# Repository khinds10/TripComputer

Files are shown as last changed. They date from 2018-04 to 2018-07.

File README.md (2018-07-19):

# TripComputer - GPS Trip Computer & Weather Module for your vehicle

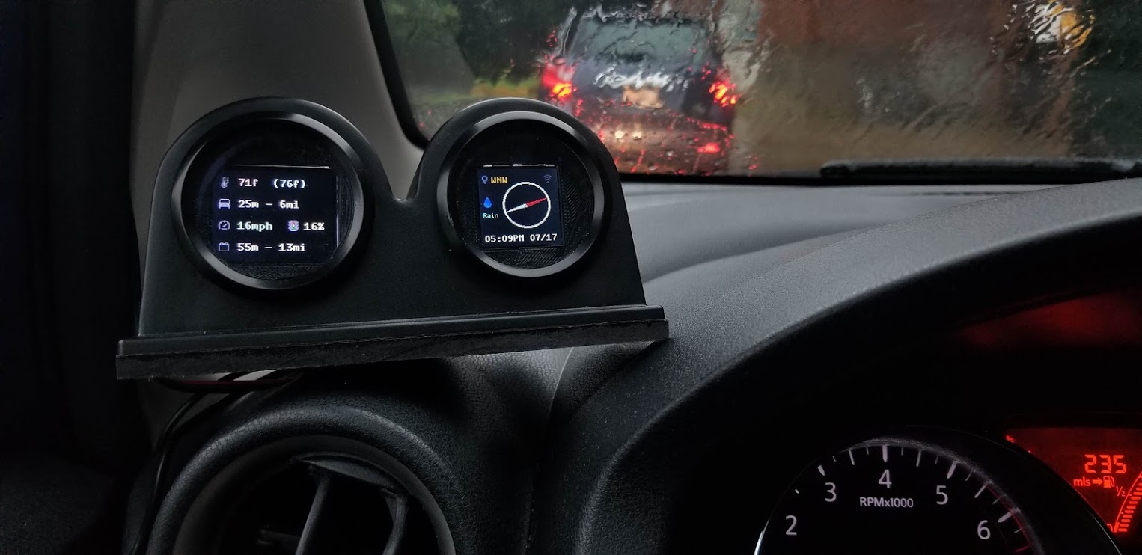
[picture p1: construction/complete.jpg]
Completed


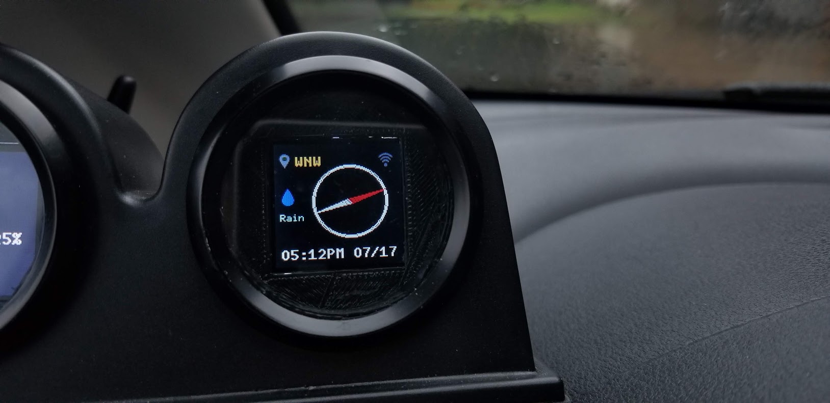
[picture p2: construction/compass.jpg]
Compass


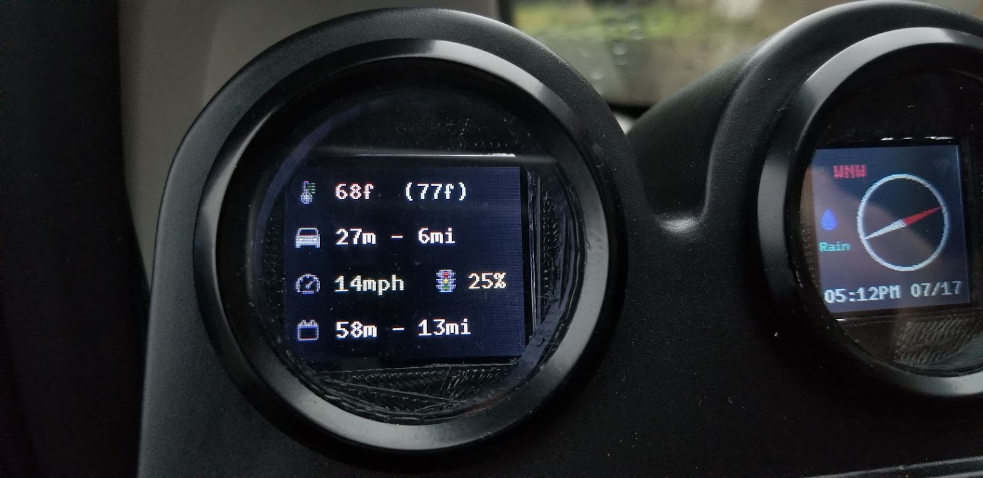
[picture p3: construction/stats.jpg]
Driving Statistics


#### Flashing RaspberriPi Hard Disk / Install Required Software (Using Ubuntu Linux)

Download "RASPBIAN JESSIE LITE VERSION"
https://www.raspberrypi.org/downloads/raspbian/

**Create your new hard disk for DashboardPI**
>Insert the microSD to your computer via USB adapter and create the disk image using the `dd` command
>
> Locate your inserted microSD card via the `df -h` command, unmount it and create the disk image with the disk copy `dd` command
> 
> $ `df -h`
> */dev/sdb1       7.4G   32K  7.4G   1% /media/XXX/1234-5678*
> 
> $ `umount /dev/sdb1`
> 
> **Caution: be sure the command is completely accurate, you can damage other disks with this command**
> 
> *if=location of RASPBIAN JESSIE FULL VERSION image file*
> *of=location of your microSD card*
> 
> $ `sudo dd bs=4M if=/path/to/raspbian-jessie-lite.img of=/dev/sdb`
> *(note: in this case, it's /dev/sdb, /dev/sdb1 was an existing factory partition on the microSD)*

**Setting up your RaspberriPi**

*Insert your new microSD card to the raspberrypi and power it on with a monitor connected to the HDMI port*

Login
> user: **pi**
> pass: **raspberry**

Change your account password for security (from terminal)
>`sudo passwd pi`

Enable RaspberriPi Advanced Options (from terminal)
>`sudo raspi-config`

Choose:
`1 Expand File System`

`9 Advanced Options`
>`A2 Hostname`
>*change it to "TripComputer"*
>
>`A4 SSH`
>*Enable SSH Server*
>
>`A7 I2C`
>*Enable i2c interface*

**Enable the English/US Keyboard**

>`sudo nano /etc/default/keyboard`

> Change the following line:
>`XKBLAYOUT="us"`

**Reboot PI for Keyboard layout changes / file system resizing to take effect**
>$ `sudo shutdown -r now`

**Auto-Connect to your WiFi**

>`sudo nano /etc/wpa_supplicant/wpa_supplicant.conf`

Add the following lines to have your raspberrypi automatically connect to your home WiFi
*(if your wireless network is named "linksys" for example, in the following example)*

	network={
	   ssid="linksys"
	   psk="WIRELESS PASSWORD HERE"
	}

**Reboot PI to connect to WiFi network**

>$ `sudo shutdown -r now`
>
>Now that your PI is finally on the local network, you can login remotely to it via SSH.
>But first you need to get the IP address it currently has.
>
>$ `ifconfig`
>*Look for "inet addr: 192.168.XXX.XXX" in the following command's output for your PI's IP Address*

**Go to another machine and login to your raspberrypi via ssh**

> $ `ssh pi@192.168.XXX.XXX`

**Start Installing required packages**

>$ `sudo apt-get update && sudo apt-get upgrade`
>
>$ `sudo apt-get install build-essential git gpsd gpsd-clients i2c-tools libi2c-dev python3 python3-pip python-dev python-gps python-imaging python-pip python-smbus rpi.gpio vim python-psutil`
>
>$ `sudo pip install RPi.GPIO`

**Update local timezone settings**

>$ `sudo dpkg-reconfigure tzdata`

`select your timezone using the interface`

**Setup the simple directory `l` command [optional]**

>`vi ~/.bashrc`
>
>*add the following line:*
>
>`alias l='ls -lh'`
>
>`source ~/.bashrc`

**Fix VIM default syntax highlighting [optional]**

>`sudo vi  /etc/vim/vimrc`
>
>uncomment the following line:
>
>_syntax on_

### Supplied needed

2" 320x240 TFT LCD Digole Display (x2)

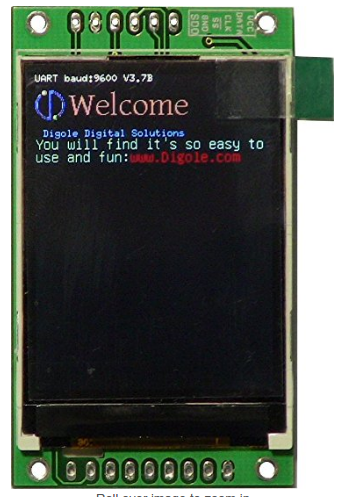
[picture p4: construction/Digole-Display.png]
Digole Display


DHT11 Humidistat

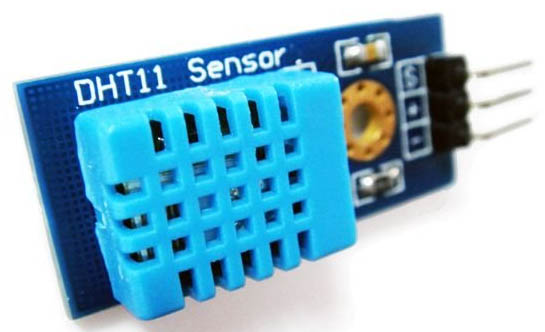
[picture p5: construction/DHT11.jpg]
DHT11


RaspberriPi Zero

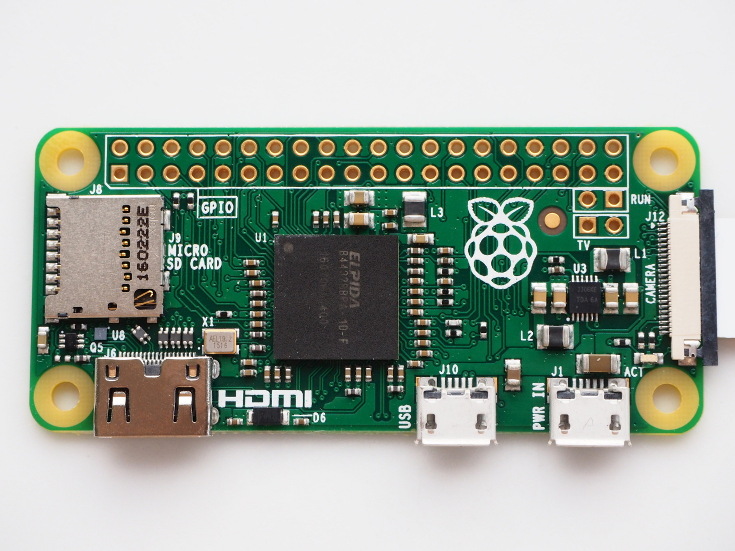
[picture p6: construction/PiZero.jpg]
RaspberriPi Zero


Adafruit GPS Breakout

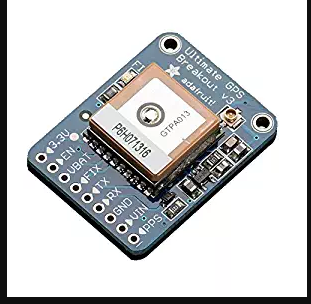
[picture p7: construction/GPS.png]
Adafruit GPS Breakout


52mm 2in Gauges - used for the glass / and screen surrounds

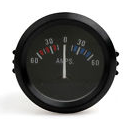
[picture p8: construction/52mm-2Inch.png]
52mm 2in Gauges


2 Gauge mount container

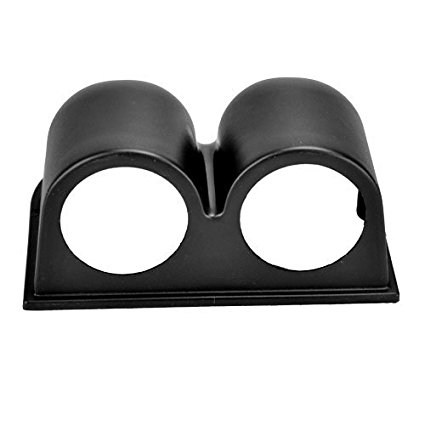
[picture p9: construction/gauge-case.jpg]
gauge container


### Print the Enclosure

In the "3DPrint/" folder of this project, print the gauges-final.stl file which will produce the Digole display surrounds needed to mount the 2 screens inside the gauge mount container.

### Building the Trip Computer

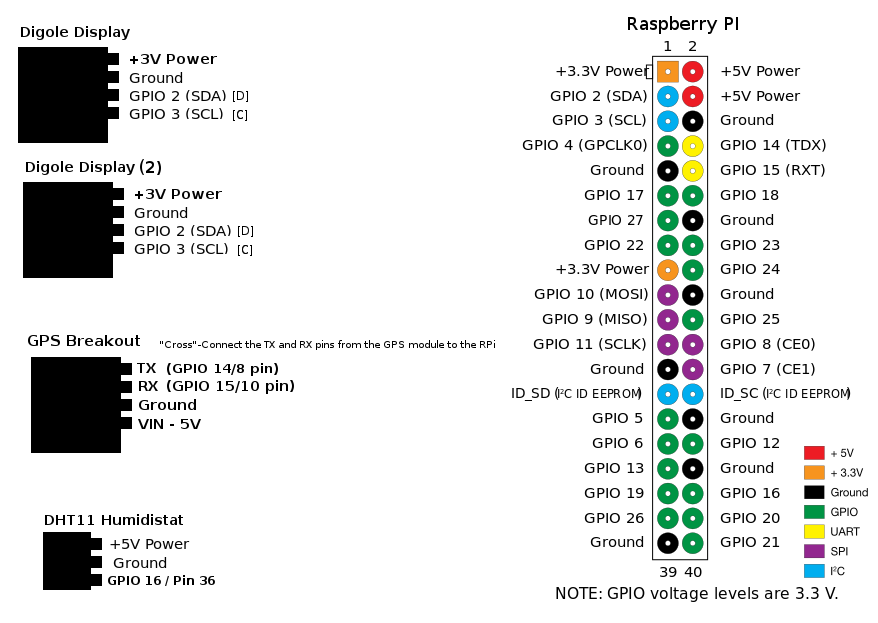
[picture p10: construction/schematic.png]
Schematic


#### Connect the following Devices the pins on the Pi Zero

Digole (each):         3v / GND / SDA / SCL

DHT11:          5v / GPIO 16 (36) / GND

### Connect the GPS USB Module to RaspberriPi via HW UART connections

Using HW UART for the GPS module requires the following to free the UART connection up on your Pi.

"Cross"-Connect the TX and RX pins from the GPS module to the RPi TX (GPIO 14/8 pin) and RX (GPIO 15/10 pin) -- [TX goes to RX on the device and vice versa.]
Connect RPi 5V to the VIN pin and the GPS module GND pin to an available RPi GND pin.

### Final Assembly

Cut a piece of wood for the bottom to hold the compenents inside the gauge casing.

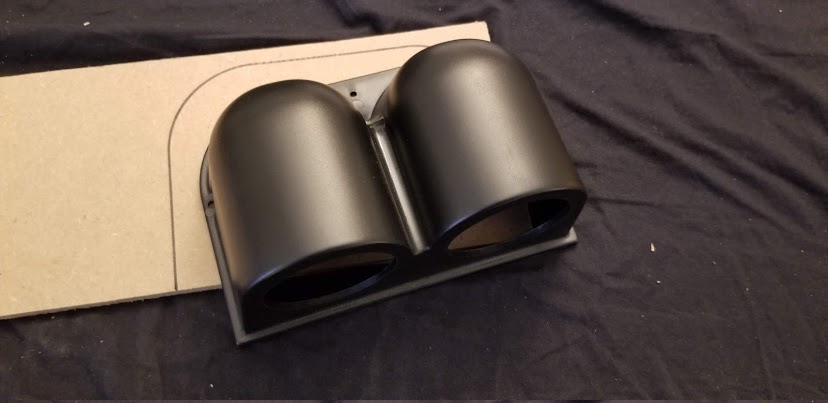
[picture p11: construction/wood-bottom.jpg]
Wood Mount


Take the 2 52mm 2in Gauges and cut the tops off, we're just using the glass and surround to mount our own displays, the Digole displays.
Glue them into place with hot glue.

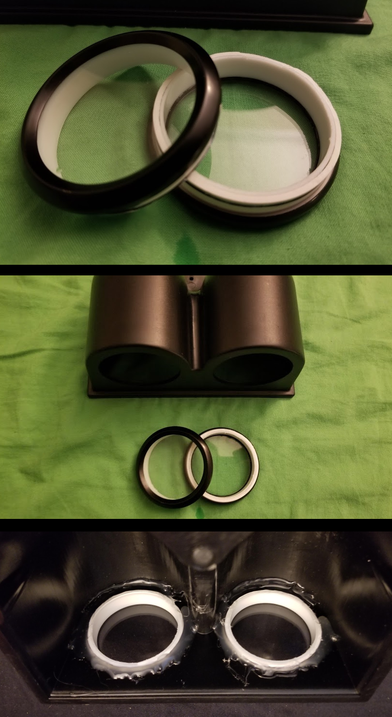
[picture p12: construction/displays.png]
Mount Displays


Using the schematic above wire together the components using solder to make everything strong and permanent.

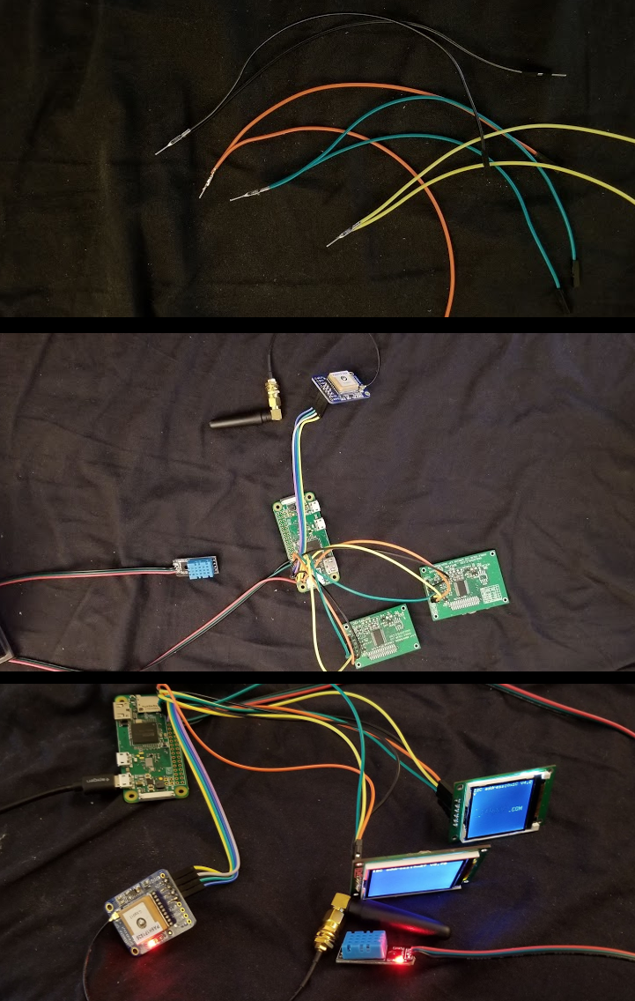
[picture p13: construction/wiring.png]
Wiring


Mount the components inside the dual gauge casing, use the 3D printed surrounds to have the square shaped Digole displays fit to the circular gauge windows.

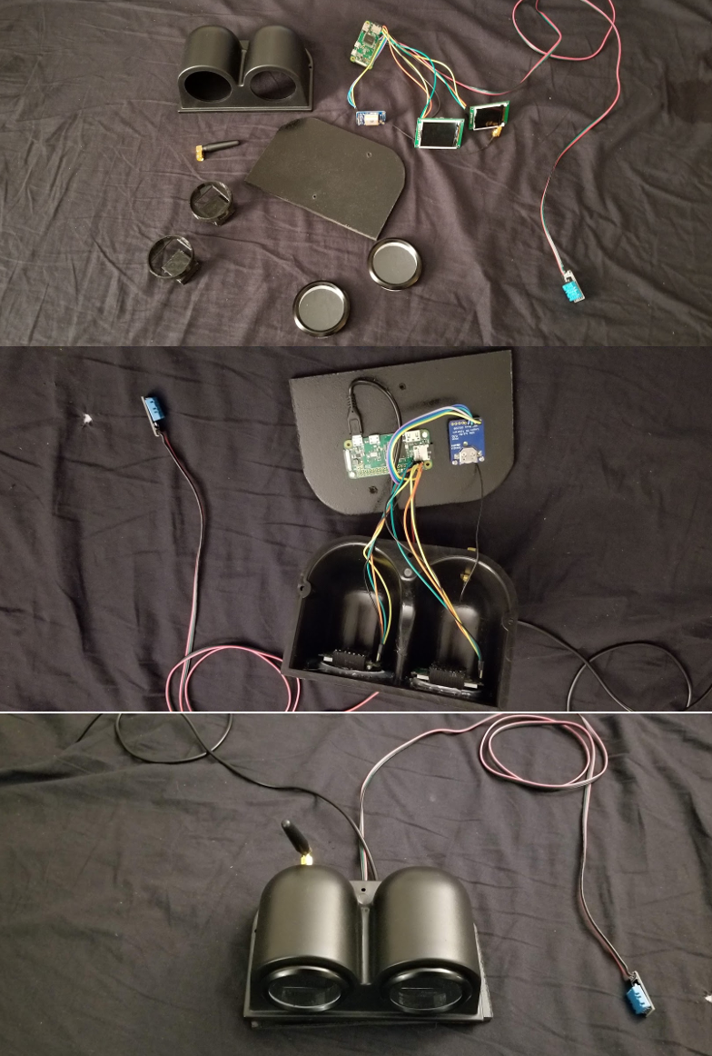
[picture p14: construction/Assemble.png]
Mount Wiring


#### Configure your Pi to use the GPS Module on UART

sudo vi /boot/cmdline.txt

change:

`dwc_otg.lpm_enable=0 console=ttyAMA0,115200 kgdboc=ttyAMA0,115200 console=tty1 root=/dev/mmcblk0p2 rootfstype=ext4 elevator=deadline rootwait`

to:

`dwc_otg.lpm_enable=0 console=tty1 root=/dev/mmcblk0p2 rootfstype=ext4 elevator=deadline rootwait`

(eg, remove console=ttyAMA0,115200 and if there, kgdboc=ttyAMA0,115200)

Note you might see console=serial0,115200 or console=ttyS0,115200 and should remove those parts of the line if present.

Run the following commands:

`sudo systemctl stop serial-getty@ttyAMA0.service`

`sudo systemctl disable serial-getty@ttyAMA0.service`

#### GPS Module Install

For testing force your USB device to connect to gpsd

`sudo gpsd /dev/ttyS0 -F /var/run/gpsd.sock`

`sudo systemctl stop gpsd.socket`

`sudo killall gpsd`

`sudo dpkg-reconfigure gpsd`

`sudo vi /etc/default/gpsd`

> \# Default settings for gpsd.
> START_DAEMON="true"
> GPSD_OPTIONS="-n"
> DEVICES="/dev/ttyS0"
> USBAUTO="false"
> GPSD_SOCKET="/var/run/gpsd.sock"

Make sure the command is working

`cgps -s`

#### DHT11 Install

`cd ~`

`git clone https://github.com/adafruit/Adafruit_Python_DHT.git`

`cd Adafruit_Python_DHT/`

`sudo python setup.py install`

`sudo python ez_setup.py`

`cd examples/`

`vi simpletest.py`

Change the following line:

> sensor = Adafruit_DHT.DHT11

Comment the line out

> pin = 'P8_11'

Uncomment the line and change the pin number to 16

> pin = 16

Run the test

`python simpletest.py`

> You should see a metric reading of Temp and Humidity displayed on the command line.

#### Setup and Run the scripts

`cd ~`

`git clone https://github.com/khinds10/TripComputer.git`

### Install driving monitoring tools & DB Logging

`sudo apt-get install ifstat memcached python-memcache postgresql postgresql-contrib python-psycopg2`

`sudo vi /etc/postgresql/9.4/main/pg_hba.conf`

> Add the following line to the end of the file:
>
>local all pi password

`sudo -i -u postgres`

`psql`

`create role pi password 'password here';`

`alter role pi login;`

`alter role pi superuser;`

`\du`

>(you should see your PI user with the permissions granted)

`create database driving_statistics;`

`\q`

`exit`

`psql -d driving_statistics`

Run the following queries:

>CREATE TABLE driving\_stats (
> id serial,
> time timestamp without time zone NOT NULL,
> new\_trip\_start timestamp without time zone NULL,
> gps\_latitude double precision	,
> gps\_longitude double precision,
> gps\_altitude real,
> gps\_speed real,
> gps\_climb real,
> gps\_track real,
> locale\_address text,
> locale\_area text,
> locale\_city text,
> locale\_county text,
> locale\_country text,
> locale\_zipcode text,
> inside\_temp real,
> inside\_hmidty real,
> weather\_time timestamp,
> weather\_summary text,
> weather\_icon text,
> weather\_apparentTemperature real,
> weather\_humidity real,
> weather\_precipIntensity real,
> weather\_precipProbability real,
> weather\_windSpeed real
>);
>
>CREATE UNIQUE INDEX time_idx ON driving\_stats (time);

### Hack required to get GPSD working with UART connection on reboot

`sudo su`

`crontab -e`

`@reboot /bin/sleep 5; killall gpsd`

`@reboot /bin/sleep 10; /usr/sbin/gpsd /dev/ttyS0 -F /var/run/gpsd.sock`

### Create the logs folder for the data to be saved

`mkdir /home/pi/TripComputer/computer/logs`

### Setup the scripts to run at boot

`crontab -e`

Add the following lines

>`@reboot /bin/sleep 15; nohup python /home/pi/TripComputer/computer/mtk3339.py > /home/pi/TripComputer/computer/mtk3339.log 2>&1`
>
>`@reboot /bin/sleep 18; nohup python /home/pi/TripComputer/computer/driving.py > /home/pi/TripComputer/computer/driving.log 2>&1`
>
>`@reboot /bin/sleep 19; nohup python /home/pi/TripComputer/computer/address.py > /home/pi/TripComputer/computer/address.log 2>&1`
>
>`@reboot /bin/sleep 30; nohup python /home/pi/TripComputer/computer/gauges.py > /home/pi/TripComputer/computer/gauges.log 2>&1`
>
>`@reboot /bin/sleep 21; nohup python /home/pi/TripComputer/computer/locale.py > /home/pi/TripComputer/computer/locale.log 2>&1`
>
>`@reboot /bin/sleep 22; nohup python /home/pi/TripComputer/computer/notification.py > /home/pi/TripComputer/computer/notification.log 2>&1`
>
>`@reboot /bin/sleep 24; nohup python /home/pi/TripComputer/computer/temperature.py > /home/pi/TripComputer/computer/temperature.log 2>&1`
>
>`@reboot /bin/sleep 25; nohup python /home/pi/TripComputer/computer/upload.py > /home/pi/TripComputer/computer/upload.log 2>&1`
>
>`@reboot /bin/sleep 26; nohup python /home/pi/TripComputer/computer/weather.py > /home/pi/TripComputer/computer/weather.log 2>&1`
>
>`@reboot /bin/sleep 30; nohup python /home/pi/TripComputer/computer/stats.py > /home/pi/TripComputer/computer/stats.log 2>&1`
>

Setup the root user crontab to make sure the GPS module connects correctly

`sudo su`

`crontab -e`

Add the following lines

>`@reboot /bin/sleep 5; systemctl stop gpsd.socket`
>
>`@reboot /bin/sleep 8; killall gpsd`
>
>`@reboot /bin/sleep 12; /usr/sbin/gpsd /dev/ttyS0 -F /var/run/gpsd.sock`

### Finally create the local settings needed to run the trip computer

Find the file `/computer/includes/settings.shadow.py`

Create your own version of the settings file named simply `settings.py`

##### forecast.io API key for local weather information

`weatherAPIURL = 'https://api.forecast.io/forecast/'`

`weatherAPIKey = 'API KEY HERE'`

##### if you have the device hub project running (https://github.com/khinds10/DeviceHub)

`devicesServer = 'http://my.server.com'`

##### if you have the dashboard phone project running (https://github.com/khinds10/RetroDashboard)

`dashboardServer = 'http://my.server.com'`

#### Mount on Dash

Completed

#### Mount Humidistat away from direct Sun
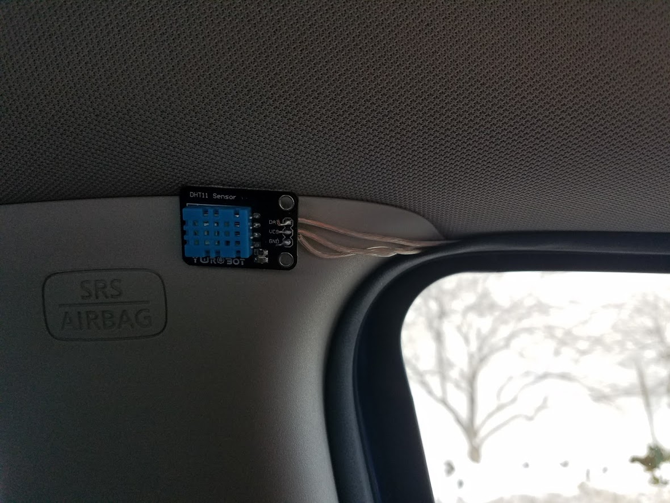
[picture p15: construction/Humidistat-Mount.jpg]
Humidistat Mount


### Reboot your RPi and you should be ready to go!
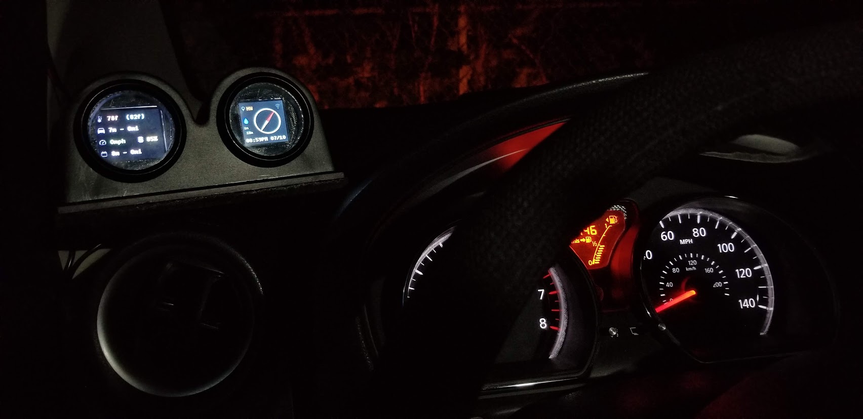
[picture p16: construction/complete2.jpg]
Complete


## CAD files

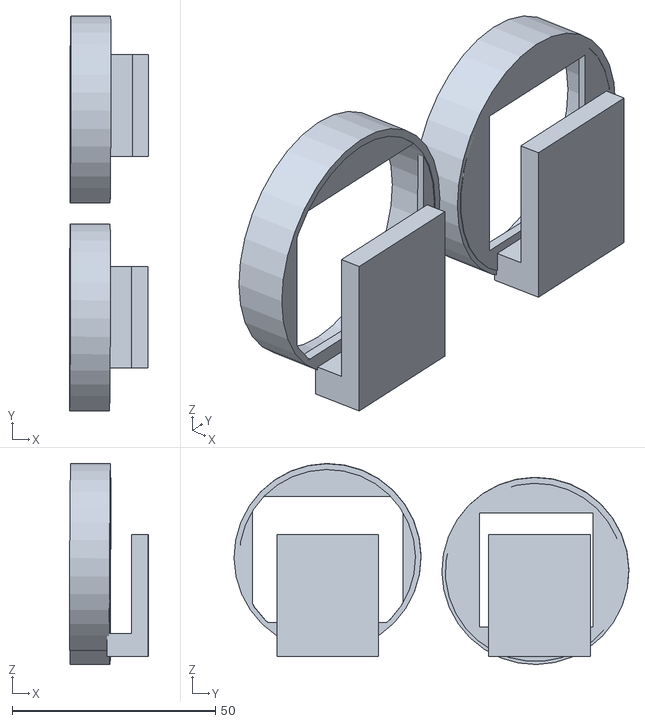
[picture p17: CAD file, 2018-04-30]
3DPrint/guages-final.stl
19.5 x 97.1 x 49.4

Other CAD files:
3DPrint/guages-final.blend
3DPrint/guages.blend

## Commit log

2018-04-12 added digole driver with I2c address changing option
2018-04-30 added logging data w/libraries and 3D print models
    [guages-final.blend, guages-final.stl, guages.blend]
2018-06-05 begin to get results from the db to persist to the device hub project
2018-06-22 updated readme for the PI3 uart settings
2018-07-18 added final sampled log files and images for readme
